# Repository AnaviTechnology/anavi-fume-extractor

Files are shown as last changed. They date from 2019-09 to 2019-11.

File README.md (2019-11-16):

# ANAVI Fume Extractor

ANAVI Fume Extractor is an open source hardware development board with ESP8266 and connector for 5V USB-powered fan for absorbing smoke. It features:

* ESP8266 WiFi microcontroller
* Connector for 5V DC fan
* Dedicated slot for I2C OLED display
* Slots for up to 3 plug and play I2C sensors for temperature, barometric pressure, humidity and light
* Slot for analog MQ gas sensor
* UART (Universal asynchronous receiver/transmitter) pins for debugging

[Open source software for ANAVI Fume Extractor written as an Arduino sketch is also available at GitHub](https://github.com/AnaviTechnology/anavi-fume-extractor-sw).

# License

The project is released under the [Creative Commons Attribution-ShareAlike 4.0 International (CC BY-SA 4.0)](https://creativecommons.org/licenses/by-sa/4.0/).

Note: This is a human-readable summary of (and not a substitute for) the [license](https://creativecommons.org/licenses/by-sa/4.0/legalcode).

You are free to:

Share — copy and redistribute the material in any medium or format Adapt — remix, transform, and build upon the material for any purpose, even commercially. The licensor cannot revoke these freedoms as long as you follow the license terms. Under the following terms:

Attribution — You must give appropriate credit, provide a link to the license, and indicate if changes were made. You may do so in any reasonable manner, but not in any way that suggests the licensor endorses you or your use. ShareAlike — If you remix, transform, or build upon the material, you must distribute your contributions under the same license as the original. No additional restrictions — You may not apply legal terms or technological measures that legally restrict others from doing anything the license permits. Notices:

You do not have to comply with the license for elements of the material in the public domain or where your use is permitted by an applicable exception or limitation. No warranties are given. The license may not give you all of the permissions necessary for your intended use. For example, other rights such as publicity, privacy, or moral rights may limit how you use the material.

You will have to provide a link to the original creator of the project http://www.anavi.technology on any documentation or website.

Credit can be attributed through a link to the creator website: http://www.anavi.technology

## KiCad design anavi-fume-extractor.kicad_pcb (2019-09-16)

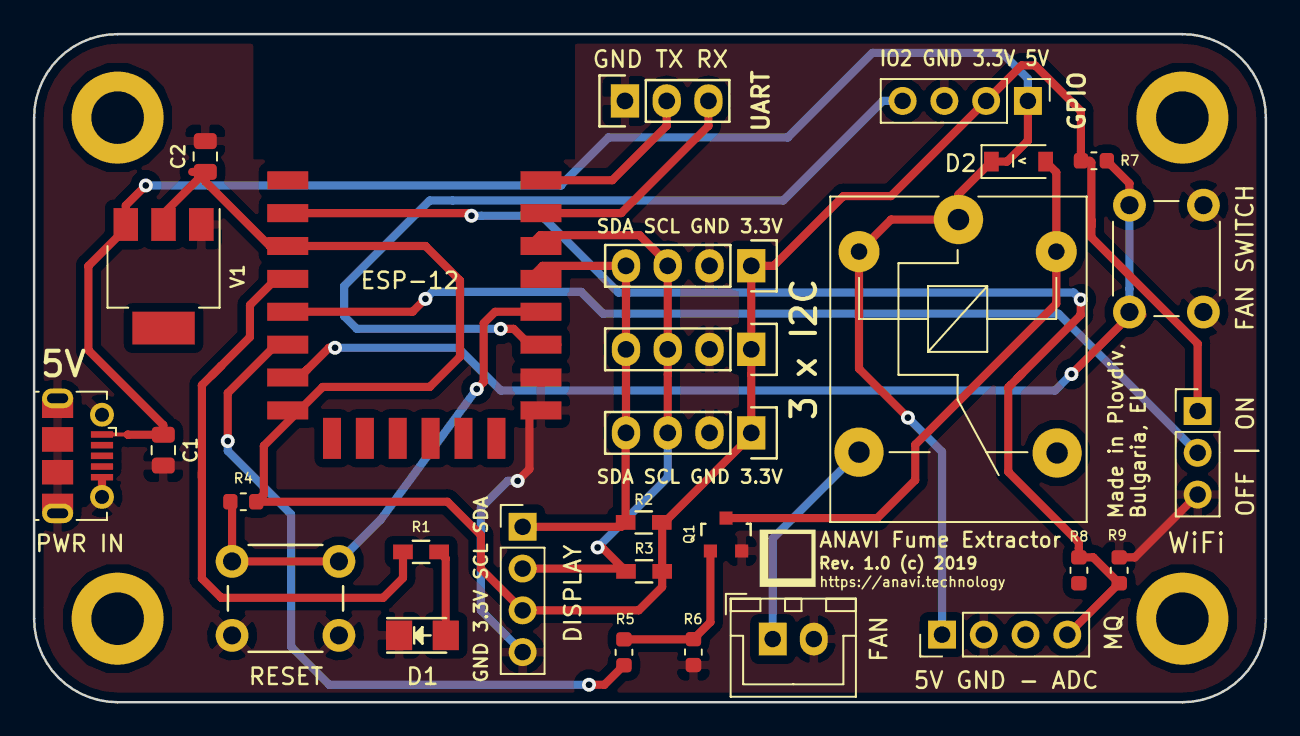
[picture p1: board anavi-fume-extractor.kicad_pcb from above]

Board: 2 copper layers, 74.9 x 40.6 mm, 29 parts (0 on the bottom side), 18 nets.

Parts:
C1, C2: 10uF; C_0805_2012Metric
D1: LED; LED_1206
D2: 1N4148W; D_SOD-123
DISPLAY: Conn_01x04; PinHeader_1x04_P2.54mm_Vertical
ESP-12: ESP-12E; ESP-12E_SMD
FAN: Conn_01x02; JST_XH_B02B-XH-A_1x02_P2.50mm_Vertical
FAN SWITCH: SW_DIP_x01; SW_PUSH_6mm_h4.3mm
GPIO: Conn_01x04; PinHeader_1x04_P2.54mm_Vertical
K1: SANYOU_SRD_Form_C; Relay_SPDT_SANYOU_SRD_Series_Form_C
MQ: Conn_01x04; PinHeader_1x04_P2.54mm_Vertical
P1: CONN_01X03; Pin_Header_Straight_1x03
PWR IN: USB_B_Micro; USB_Micro-B_Molex-105017-0001
Q1: BC817; SOT-23
R1: 68R; R_0603_HandSoldering
R2, R3: 4,7K; R_0603_HandSoldering
R4, R7: 2K; R_0603_1608Metric
R5: 2,7K; R_0603_1608Metric
R6: 27K; R_0603_1608Metric
R8: 220K; R_0603_1608Metric
R9: 56K; R_0603_1608Metric
RESET: SW_DIP_x01; SW_PUSH_6mm_h4.3mm
U1, U2, U3: I2C_SENS_1; Pin_Header_Straight_1x04
V1: LD1117S33TR; SOT-223
WiFi: ConfigWiFi; PinHeader_1x03_P2.54mm_Vertical

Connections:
+3V3: C2.1, DISPLAY.3, ESP-12.3, ESP-12.8, GPIO.2, R2.1, R3.1, R4.2, R7.1, U1.1, U2.1, U3.1, V1.2, WiFi.1
+5V: C1.1, D2.1, GPIO.1, K1.1, K1.2, MQ.1, PWR IN.1, V1.3
GND: C1.2, C2.2, D1.1, DISPLAY.4, ESP-12.9, ESP-12.10, FAN.2, FAN SWITCH.1, GPIO.3, MQ.2, P1.1, PWR IN.5, PWR IN.6, Q1.2, R6.2, R9.2, RESET.1, U1.2, U2.2, U3.2, V1.1, WiFi.3
unnamed: D1.2, R1.2
unnamed: D2.2, K1.5, Q1.3
unnamed: ESP-12.2, MQ.4, R8.2, R9.1
unnamed: ESP-12.4, R1.1
unnamed: ESP-12.5, WiFi.2
unnamed: ESP-12.6, R5.1
unnamed: ESP-12.7, FAN SWITCH.2, R7.2
unnamed: ESP-12.11, GPIO.4
unnamed: ESP-12.12, R4.1, RESET.2
unnamed: DISPLAY.1, ESP-12.13, R2.2, U1.4, U2.4, U3.4
unnamed: DISPLAY.2, ESP-12.14, R3.2, U1.3, U2.3, U3.3
unnamed: ESP-12.15, P1.3
unnamed: ESP-12.16, P1.2
unnamed: FAN.1, K1.3
unnamed: Q1.1, R5.2, R6.1

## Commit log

2019-07-14 anavi-fume-extractor.kicad_pcb: Move capacitor
    Move capacitor C1 to be closer to the microUSB connector.
    Suggested-by: Rangel Ivanov <rangelivanov88@gmail.com>
    [anavi-fume-extractor.kicad_pcb]
2019-09-16 anavi-fume-extractor.kicad_pcb: Assembly notes
    Add notes to simplify the assembly of the board.
    [anavi-fume-extractor.kicad_pcb]

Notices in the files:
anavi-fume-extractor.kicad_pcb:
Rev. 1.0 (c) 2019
